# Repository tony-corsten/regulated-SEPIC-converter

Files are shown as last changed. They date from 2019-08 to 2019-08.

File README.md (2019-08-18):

# regulated-SEPIC-converter
# Overview
The ADP5070/5071 are integrated dual rail switching power supplies that can generate outputs of up to -39V - 39V from an input voltage of 2.85V - 15V. As an alternative to low current charge pumps, the ADP5071 is specced to deliver up to 2A on the positive rail and 1.2A on the negative rail (compared to ~50-100mV out of a typical charge pump). This makes it great for use in a system requiring high current dual rail inputs, like high-power op amps or ADCs.

Additionally, the chip has flexibility in what kind of switching architecture is employed. Typically, the chip operates in a boost architecture, and the inverting converter works on the boosted voltage. However, the chip can also employ a modern SEPIC design, where the chip can either boost *OR* buck automatically based on the board configuration. **The current configuration of the board is as a SEPIC converter.** There are two LDOs (one for each rail) at the output to regulate the output as well. _Note that the selected LDOs (LT3094 and LT3042/4) are only specced for 500mA on each regulator_. If you don't require low-noise, but do require high current, I recommend changing these out for higher current LDOs!

You can find the official documentation for the [ADP5071 chip here,](https://www.analog.com/en/products/adp5071.html) for the [LT3094 here,](https://www.analog.com/en/products/lt3094.html) and for [the LT3045 here](https://www.analog.com/en/products/lt3045.html#product-overview). This is a breakout board made in Kicad with a barrel jack power input [(the PJ-037A)](https://www.digikey.com/product-detail/en/cui-inc/PJ-037A/CP-037A-ND/1644545) and [SMA connectors for each output](https://www.amazon.com/gp/product/B00G94UK74/ref=ppx_yo_dt_b_search_asin_title?ie=UTF8&psc=1) (+/- rail for switching supply, and +/- rail for LDOs).

*_Note_*: The board is currently designed for a +/- 6V rail for a 9V battery input, which *only* works in a SEPIC design. If not using the SEPIC design, make sure to have the desired positive rail be higher than the input voltage. 

# Navigating this repo
The main folder contains relevant Kicad files (.pro, .pcb, .sch). The `gerber` directory has a PCB-fabrication ready set of gerber files. The `library` directory contains a custom kicad footprint for the PJ-037A, SMA connector and LPD3015 power inductor. There are also hand-solderable footprints for the linear regulators included. Finally, an updated `devices` library is available for the symbol for the LPD3015 (alternatively, you can make the symbol yourself as a small edit to the existing coupled inductor). 

# Board images
PCB Layout:
PCB Layout

Schematic:
Schematic

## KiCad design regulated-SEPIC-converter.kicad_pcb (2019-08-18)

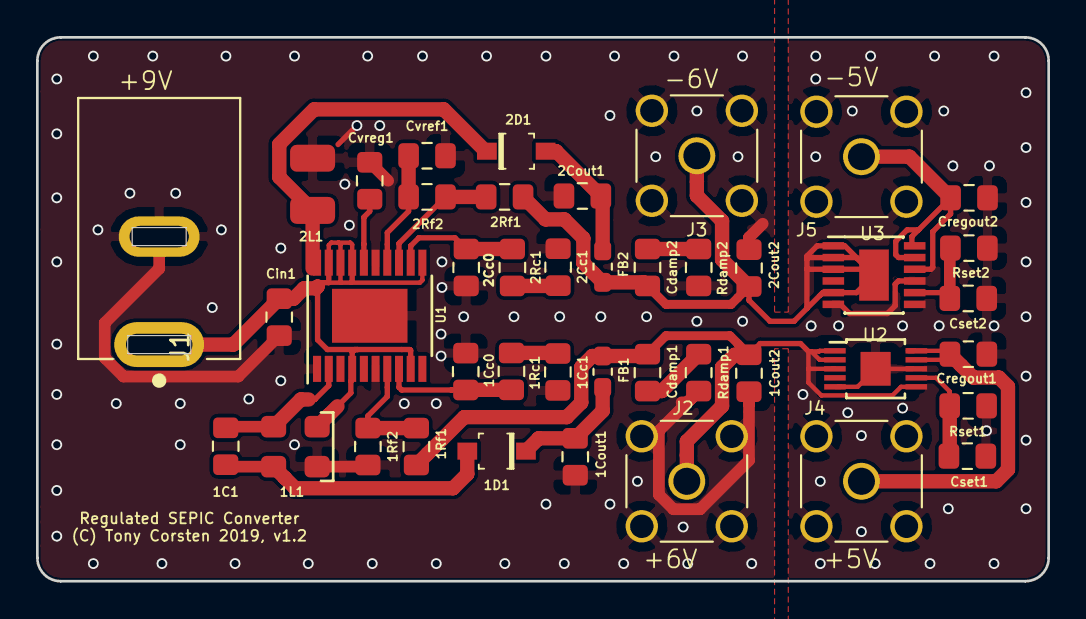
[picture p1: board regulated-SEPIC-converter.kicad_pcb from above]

Board: 2 copper layers, 56.2 x 30.2 mm, 42 parts (0 on the bottom side), 23 nets.

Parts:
1C1: 1uF; C_0805_2012Metric_Pad1.15x1.40mm_HandSolder
1Cc0, 2Cc0: 47pF; C_0805_2012Metric_Pad1.15x1.40mm_HandSolder
1Cc1: 8.2nF; C_0805_2012Metric_Pad1.15x1.40mm_HandSolder
1Cout1, 2Cout1: 10uF; C_0805_2012Metric_Pad1.15x1.40mm_HandSolder
1Cout2, 2Cout2: 10nF; C_0805_2012Metric_Pad1.15x1.40mm_HandSolder
1D1, 2D1: MBR0520LT1G; SOD-123_UPDATED
1L1: LPD3015-222; LPD3015
1Rc1: 7.32K; R_0805_2012Metric_Pad1.15x1.40mm_HandSolder
1Rf1: 84.5K; R_0805_2012Metric_Pad1.15x1.40mm_HandSolder
1Rf2: 13K; R_0805_2012Metric_Pad1.15x1.40mm_HandSolder
2Cc1: 6.8nF; C_0805_2012Metric_Pad1.15x1.40mm_HandSolder
2L1: 4.7uH; LQH32PN4R7NN0
2Rc1: 7.68K; R_0805_2012Metric_Pad1.15x1.40mm_HandSolder
2Rf1: 90.9K; R_0805_2012Metric_Pad1.15x1.40mm_HandSolder
2Rf2: 10.7K; R_0805_2012Metric_Pad1.15x1.40mm_HandSolder
Cdamp1, Cdamp2: 1uF; C_0805_2012Metric_Pad1.15x1.40mm_HandSolder
Cin1: 10uF; C_0805_2012Metric_Pad1.15x1.40mm_HandSolder
Cregout1: 4.7uF; C_0805_2012Metric_Pad1.15x1.40mm_HandSolder
Cregout2: 10uF; C_0805_2012Metric_Pad1.15x1.40mm_HandSolder
Cset1: 0.47uF; C_0805_2012Metric_Pad1.15x1.40mm_HandSolder
Cset2: 4.7uF; C_0805_2012Metric_Pad1.15x1.40mm_HandSolder
Cvref1: 1uF; C_0805_2012Metric_Pad1.15x1.40mm_HandSolder
Cvreg1: 1uF; C_0805_2012Metric_Pad1.15x1.40mm_HandSolder
FB1, FB2: MPZ1608S101A; R_0603_1608Metric_Pad1.05x0.95mm_HandSolder
J1: Barrel_Jack; PJ-037A
J2, J3, J4, J5: Conn_Coaxial; SMA_Vertical_Connector
Rdamp1, Rdamp2: 2.0; R_0805_2012Metric_Pad1.15x1.40mm_HandSolder
Rset1, Rset2: 49.9K; R_0805_2012Metric_Pad1.15x1.40mm_HandSolder
U1: ADP5071AREZ; ETSSOP-20-1EP_4.4x6.5mm_P0.65mm_EP3x4.2mm
U2: LT3042EMSE-PBF; MSOP-10-1EP_3x3mm_P0.5mm_EP1.68x1.88mm_HAND_SOLDER
U3: LT3094EMSE; MSOP-12-1EP_3x4mm_P0.65mm_EP1.65x2.85mm_HAND_SOLDER

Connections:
+3V3: 1L1.1, Cin1.1, J1.1, U1.4, U1.9, U1.11, U1.17, U1.18, U1.19
+5V: Cregout1.2, J4.1, U2.9, U2.10
+6V: 1Cout2.1, 1Rf1.1, Cdamp1.1, FB1.1, J2.1, U2.1, U2.2, U2.3, U2.6
-5V: Cregout2.2, J5.1, U3.10, U3.11, U3.12
-6V: 2Cout2.2, 2Rf1.1, Cdamp2.2, FB2.1, J3.1, U3.1, U3.2, U3.3, U3.5, U3.13
/COMP1: 1Cc0.2, 1Rc1.1, U1.8
/COMP2: 2Cc0.2, 2Rc1.1, U1.12
/FB1: 1Rf1.2, 1Rf2.2, U1.7
/FB2: 2Rf1.2, 2Rf2.2, U1.13
/SW1: 1C1.1, 1L1.2, U1.2
/SW2: 2D1.K, 2L1.1, U1.20
/VREF: 2Rf2.1, Cvref1.1, U1.14
/VREG: Cvreg1.2, U1.16
GND: 1Cc0.1, 1Cc1.1, 1Cout1.2, 1Cout2.2, 1L1.4, 1Rf2.1, 2Cc0.1, 2Cc1.1, 2Cout1.1, 2Cout2.1, 2L1.2, Cin1.2, Cregout1.1, Cregout2.1, Cset1.2, Cset2.2, Cvref1.2, Cvreg1.1, J1.2, J2.2, J3.2, J4.2, J5.2, Rdamp1.2, Rdamp2.1, Rset1.2, Rset2.2, U1.1, U1.6, U1.15, U1.21, U2.5, U2.8, U2.11, U3.6, U3.9
unnamed: 1C1.2, 1D1.A, 1L1.3
unnamed: 1Cc1.2, 1Rc1.2
unnamed: 1Cout1.1, 1D1.K, FB1.2
unnamed: 2Cc1.2, 2Rc1.2
unnamed: 2Cout1.2, 2D1.A, FB2.2
unnamed: Cdamp1.2, Rdamp1.1
unnamed: Cdamp2.1, Rdamp2.2
unnamed: Cset1.1, Rset1.1, U2.7
unnamed: Cset2.1, Rset2.1, U3.8
